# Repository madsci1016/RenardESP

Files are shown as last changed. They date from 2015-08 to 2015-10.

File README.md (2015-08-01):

# RenardESP
A ESP8266 Wifi Adapter for Renard based Christmas Light Dimmers.

This work is licensed under a Creative Commons Attribution-NonCommercial 4.0 International License.
This work is distributed in the hope that it will be useful, but WITHOUT ANY WARRANTY; without even the implied warranty of MERCHANTABILITY or FITNESS FOR A PARTICULAR PURPOSE.

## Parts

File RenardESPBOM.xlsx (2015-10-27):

Description | Part No | Vendor | Qty | Price/Ea | Total | 100 QTY price/ea | 100 qty price tot | Link
3.3V Reg | 497-1491-5-ND | digikey.com | 1 | 0.62 | 0.62 | 0.27 | 27 |  | 0.416 | 0.416
Capacitor Pol | 1189-2375-ND | digikey.com | 1 | 0.29 | 0.29 | 0.11008 | 11.008 |  | 0.156 | 0.156
Capacitor | 399-9776-ND | digikey.com | 1 | 0.29 | 0.29 | 0.1209 | 12.09 |  | 0.202 | 0.202
8 pin Shourded socket | 609-3530-ND | digikey.com | 1 | 0.8 | 0.8 | 0.572 | 57.2 |  | 0.595 | 0.595
8 pin connector | 609-3568-ND | digikey.com | 1 | 0.94 | 0.94 | 0.71 | 71 |  | 0.744 | 0.744
8 pin socket | 1212-1231-ND | digikey.com | 1 | 0.8 | 0.8 | 0.57 | 57 |  | 0.749 | 0.749
DIP adapter | 5746613-1-ND | digikey.com | 1 | 2.38 | 2.38 | 1.89 | 189
resistor | CF18JT1K00CT-ND | digikey.com | 1 | 0.1 | 0.1 | 0.0219 | 2.19 |  | 0.053 | 0.053
Ribbon Cable | MC24M-5-ND | digikey.com | 0.11 | 9.61 | 1.0571 | 8.92 | 98.12 |  | 9.61 | 1.0571
Header | S1011E-36-ND | digikey.com | 0.33 | 2.34 | 0.7722 | 1.72 | 56.76 |  | 2.34 | 0.7722
Diode | 1N4148TACT-ND | digikey.com | 3 | 0.1 | 0.3 | 0.0224 | 6.72 |  | 0.052 | 0.156
Button | 450-1650-ND | digikey.com | 1 | 0.11 | 0.11 | 0.08 | 8
 |  |  |  |  | 0 |  | 0
PCB |  | seeed | 0.1 | 10 | 1 | 100 | 100 |  | 1.3 | 1.3
 |  |  |  |  | 0 |  | 0
 |  |  |  |  | 0 |  | 0
WIFI |  | Spark | 1 | 5.56 | 5.56 | 5.56 | 556 |  |  | 5.56
 |  |  |  |  | 0 |  | 0
 |  |  |  |  | 0 |  | 0
 |  |  |  |  | 0 |  | 0
 |  |  |  |  |  |  | 0
 |  |  |  |  |  |  |  |  | 14.8 | 3.7
 |  |  |  |  |  |  |  |  | 15.3 | 3.825
 |  |  |  | Total | 15.0193 |  | 1252.088 |  | 12.52088

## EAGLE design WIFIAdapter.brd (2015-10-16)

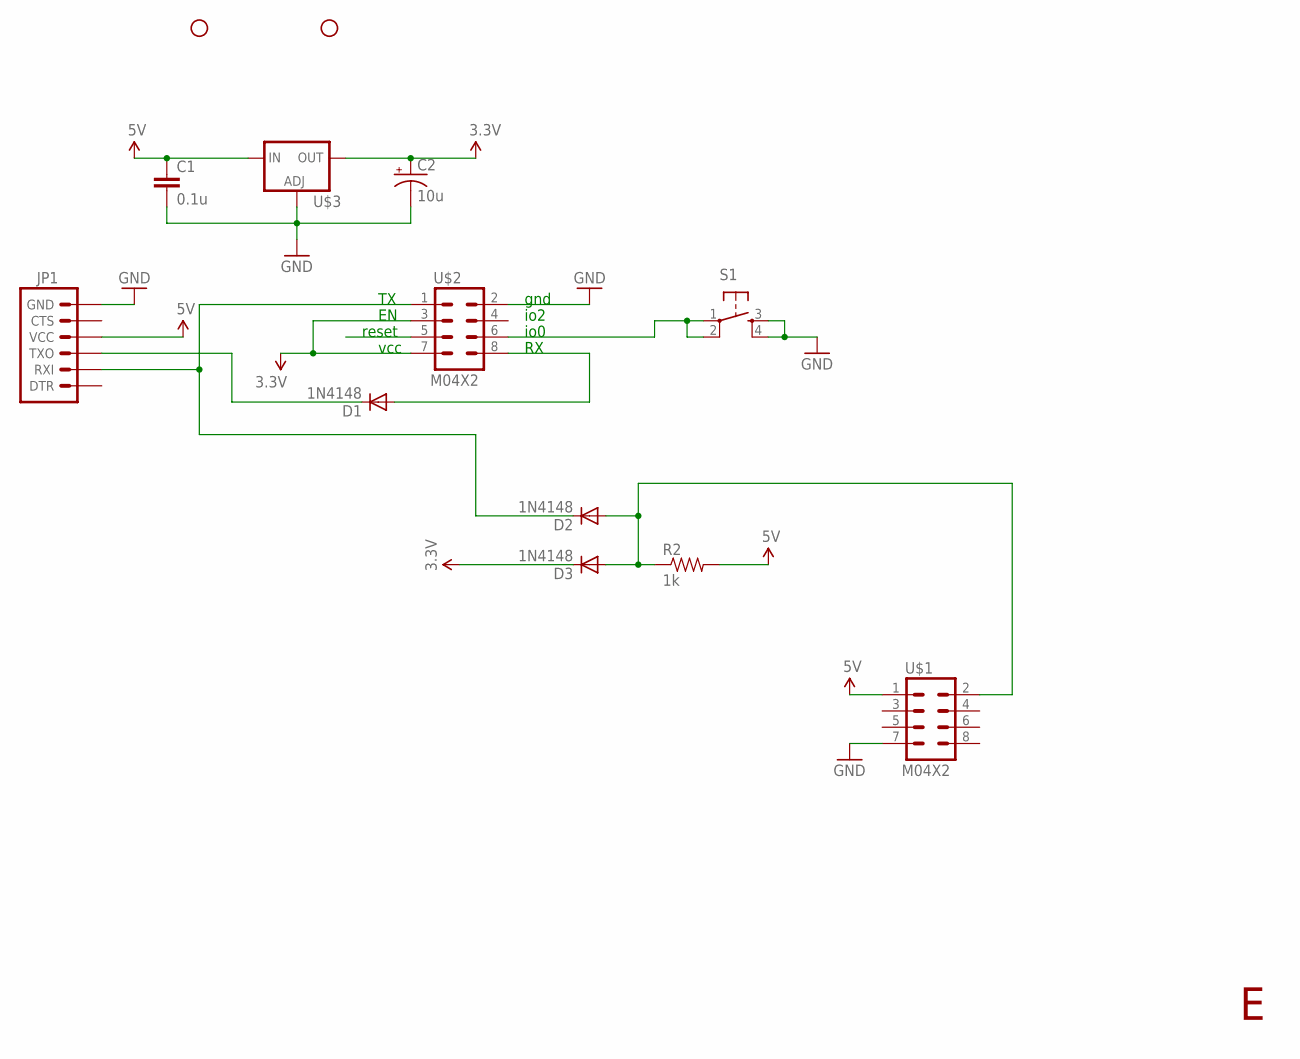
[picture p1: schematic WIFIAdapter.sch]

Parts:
C1: 0.1u; CAP-PTH-SMALLEZ
C2: 10u; CPOL-RADIAL-10UF-25V
D1, D2, D3: 1N4148; DO35-7
JP1: ARDUINO_SERIAL_PROGRAMLOCK; 1X06_LOCK
R2: 1k; AXIAL-0.3EZ
S1: TAC_SWITCHPTH; TACTILE-PTH
STANDOFF1, STANDOFF2: STAND-OFFTIGHT; STAND-OFF-TIGHT
U$1, U$2: M04X2; 2X4
U$3: LM317TS; 317TS

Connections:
3.3V: C2.1 (+), D3.C, U$2.3, U$2.7, U$3.2 (OUT)
5V: C1.1, JP1.4 (VCC), R2.P$2 (2), U$1.1, U$3.3 (IN)
GND: C1.2, C2.2 (-), JP1.6 (GND), S1.3, S1.4, U$1.7, U$2.2, U$3.1 (ADJ)
unnamed: S1.1, S1.2, U$2.6
unnamed: D1.C, JP1.3 (TXO)
unnamed: D2.A, D3.A, R2.P$1 (1), U$1.2
RX: D1.A, U$2.8
TX: D2.C, JP1.2 (RXI), U$2.1

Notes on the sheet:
reset
vcc
gnd
io2
io0

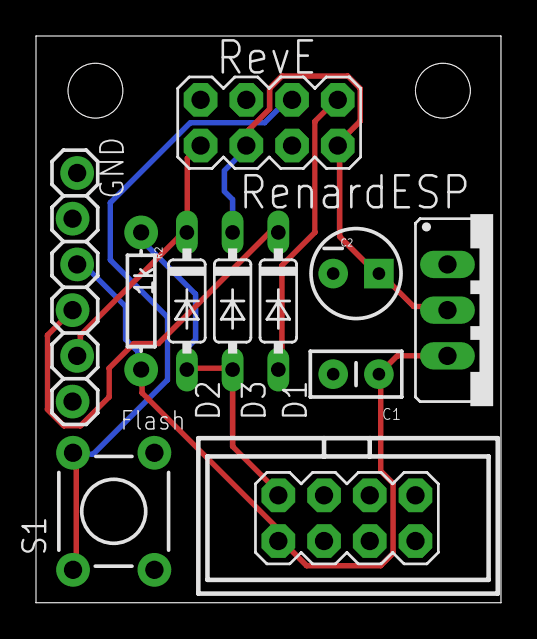
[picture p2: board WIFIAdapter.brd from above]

Board: 2 copper layers, 25.8 x 31.5 mm, 13 parts (0 on the bottom side), 8 nets.

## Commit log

2015-08-01 Initial Commit
    The Beginning.
    [RenardESPBOM.xlsx, WIFIAdapter.brd, WIFIAdapter.sch]
2015-08-01 Changed Settings Clear to use IO2
    Changed Setting clear jumper to short IO2 to ground. Turns out there is
    no pulldown resistors in the ESP, so plan to use IO0 twice doesn't work.
2015-08-03 Processed for SeeedStudo PCB service
    Includes CAM files for Seeed
    [WIFIAdapter.brd]
2015-09-22 Changed Capacitor in BOM
    Bigger!
    [RenardESPBOM.xlsx]
2015-10-16 RevE with 8 pin DIP adapter
    Trade the break away PCB adapter for a COTS ribbon cable DIP adapter.
    [RenardESPBOM.xlsx, WIFIAdapter.brd, WIFIAdapter.sch]
2015-10-27 Updated BOM
    Now includes button
    [RenardESPBOM.xlsx]

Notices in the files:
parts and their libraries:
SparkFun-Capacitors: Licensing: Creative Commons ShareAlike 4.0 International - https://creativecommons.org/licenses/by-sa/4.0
